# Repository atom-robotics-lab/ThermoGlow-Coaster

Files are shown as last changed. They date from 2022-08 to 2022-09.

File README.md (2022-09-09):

# Temperature Controlled LED Coaster



This project is an ESP12E based Temperature Controlled Smart Coaster. The project uses the following:
 * ESP12E Module
 * 12 x WS2812B SMD LEDs
 * MLX90614 Temperature Sensor I2C Module
 * Power Bank Charge-Boost Module for charging & boosting 3.7V of Li-Ion cell to 5V.
 * PCB Design was made using KICAD.

 This Project was made in Partnership with [hnhcart.com](https://www.hnhcart.com/) as sponsers and mentors.

 # Schematic
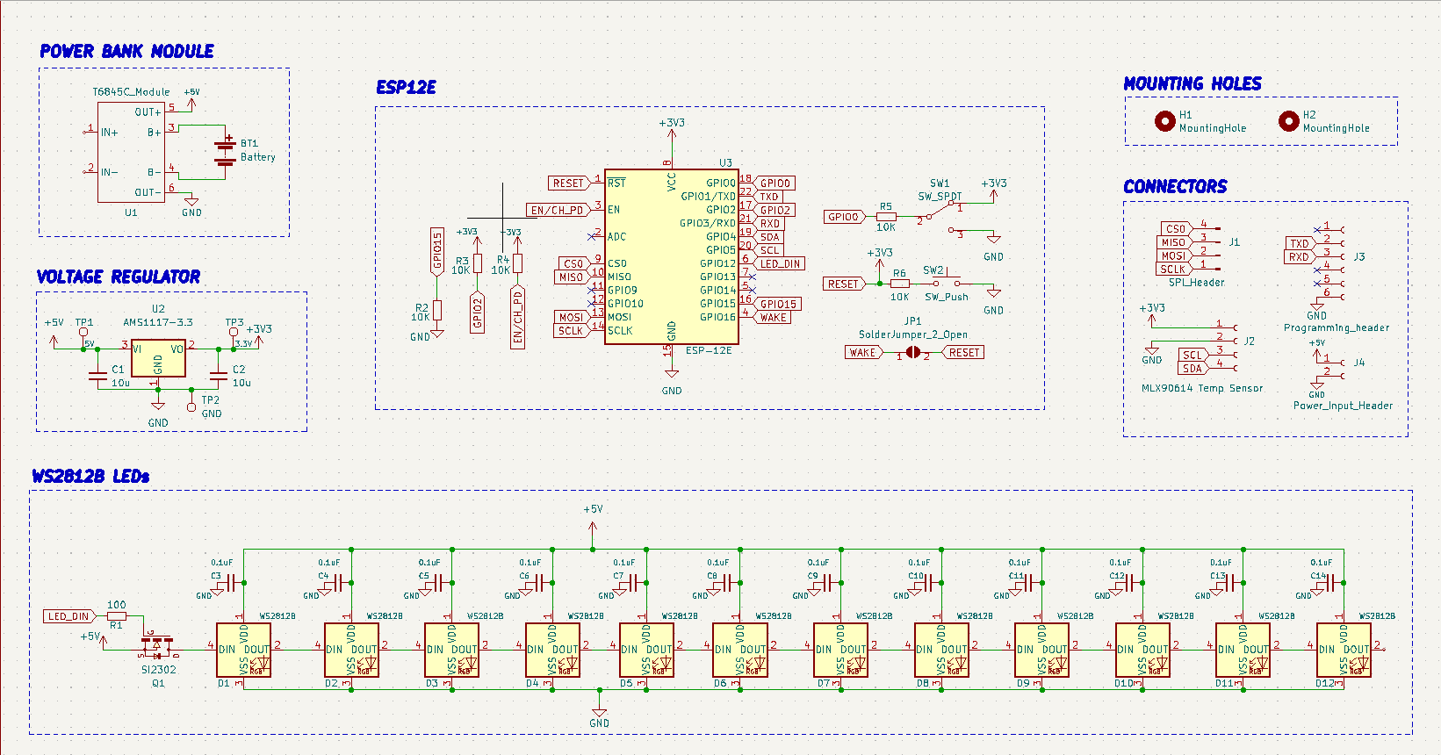
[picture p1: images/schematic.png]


# PCB Design
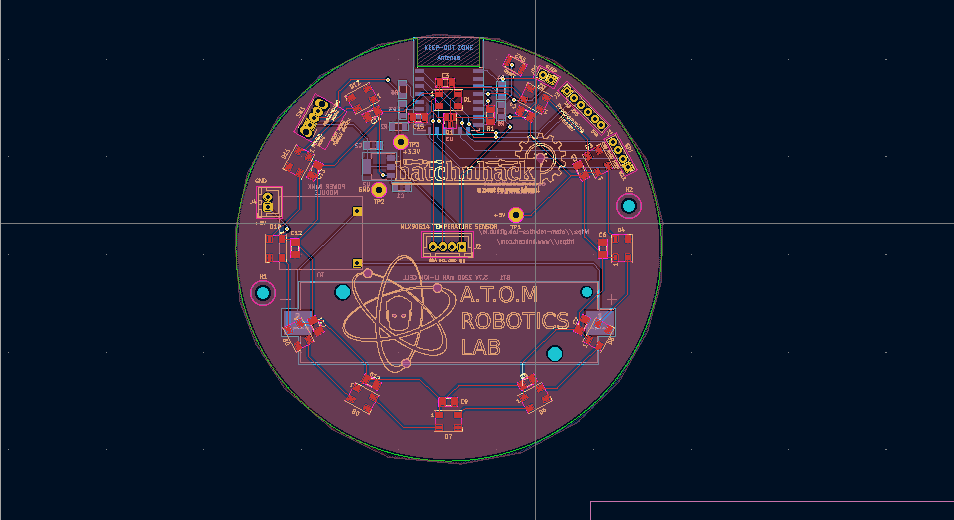
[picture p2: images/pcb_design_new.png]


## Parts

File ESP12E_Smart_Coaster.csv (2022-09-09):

Source: | /home/singh/projects/ESP12E_Smart_Coaster/ESP12E_Smart_Coaster.kicad_sch
Date: | Fri 09 Sep 2022 07:27:45 PM IST
Tool: | Eeschema 6.0.7-f9a2dced07~116~ubuntu20.04.1
Generator: | /usr/share/kicad/plugins/bom_csv_grouped_by_value_with_fp.py
Component Count: | 50
Ref | Qnty | Value | Cmp name | Footprint | Description | Vendor
BT1, | 1 | Battery | Battery | Battery:BatteryHolder_Keystone_1042_1x18650 | Multiple-cell battery
C1, C2, | 2 | 10u | C_Small | Capacitor_SMD:C_1206_3216Metric_Pad1.33x1.80mm_HandSolder | Unpolarized capacitor, small symbol
C3, C4, C5, C6, C7, C8, C9, C10, C11, C12, C13, C14, | 12 | 0.1uF | C_Small | Capacitor_SMD:C_1206_3216Metric_Pad1.33x1.80mm_HandSolder | Unpolarized capacitor, small symbol
C15, | 1 | 100uF | C_Small | Capacitor_SMD:C_1206_3216Metric_Pad1.33x1.80mm_HandSolder | Unpolarized capacitor, small symbol
D1, D2, D3, D4, D5, D6, D7, D8, D9, D10, D11, D12, | 12 | WS2812B | WS2812B | LED_SMD:LED_WS2812B_PLCC4_5.0x5.0mm_P3.2mm | RGB LED with integrated controller
H1, H2, | 2 | MountingHole | MountingHole | MountingHole:MountingHole_3.2mm_M3 | Mounting Hole without connection
J1, | 1 | SPI_Header | Conn_01x04_Male | Connector_PinHeader_2.54mm:PinHeader_1x04_P2.54mm_Vertical | Generic connector, single row, 01x04, script generated (kicad-library-utils/schlib/autogen/connector/)
J2, | 1 | MLX90614 Temp Sensor | Conn_01x04_Female | Connector_JST:JST_XH_B4B-XH-A_1x04_P2.50mm_Vertical | Generic connector, single row, 01x04, script generated (kicad-library-utils/schlib/autogen/connector/)
J3, | 1 | Programming_header | Conn_01x06_Female | Connector_PinSocket_2.54mm:PinSocket_1x06_P2.54mm_Vertical | Generic connector, single row, 01x06, script generated (kicad-library-utils/schlib/autogen/connector/)
J4, | 1 | Power_Input_Header | Conn_01x02_Female | Connector_JST:JST_XH_B2B-XH-A_1x02_P2.50mm_Vertical | Generic connector, single row, 01x02, script generated (kicad-library-utils/schlib/autogen/connector/)
JP1, | 1 | SolderJumper_2_Open | SolderJumper_2_Open | Connector_PinHeader_2.54mm:PinHeader_1x02_P2.54mm_Vertical | Solder Jumper, 2-pole, open
Q1, | 1 | SI2302 | SI2302 | Package_TO_SOT_SMD:SOT-23
R1, | 1 | 100 | R_Small | Resistor_SMD:R_1206_3216Metric_Pad1.30x1.75mm_HandSolder | Resistor, small symbol
R2, R3, R4, R5, R6, | 5 | 10K | R_Small | Resistor_SMD:R_1206_3216Metric_Pad1.30x1.75mm_HandSolder | Resistor, small symbol
SW1, | 1 | SW_SPDT | SW_SPDT | Button_Switch_THT:SW_CuK_OS102011MA1QN1_SPDT_Angled | Switch, single pole double throw
SW2, | 1 | SW_Push | SW_Push | Button_Switch_SMD:SW_Push_SPST_NO_Alps_SKRK | Push button switch, generic, two pins
TP1, | 1 | 5V | TestPoint | TestPoint:TestPoint_Loop_D2.54mm_Drill1.5mm_Beaded | test point
TP2, | 1 | GND | TestPoint | TestPoint:TestPoint_Loop_D2.54mm_Drill1.5mm_Beaded | test point
TP3, | 1 | 3.3V | TestPoint | TestPoint:TestPoint_Loop_D2.54mm_Drill1.5mm_Beaded | test point
U1, | 1 | T6845C_Module | T6845C_Module | Power_Bank_Module:T6845C_Module
U2, | 1 | AMS1117-3.3 | AMS1117-3.3 | Package_TO_SOT_SMD:SOT-223-3_TabPin2 | 1A Low Dropout regulator, positive, 3.3V fixed output, SOT-223
U3, | 1 | ESP-12E | ESP-12E | RF_Module:ESP-12E | 802.11 b/g/n Wi-Fi Module

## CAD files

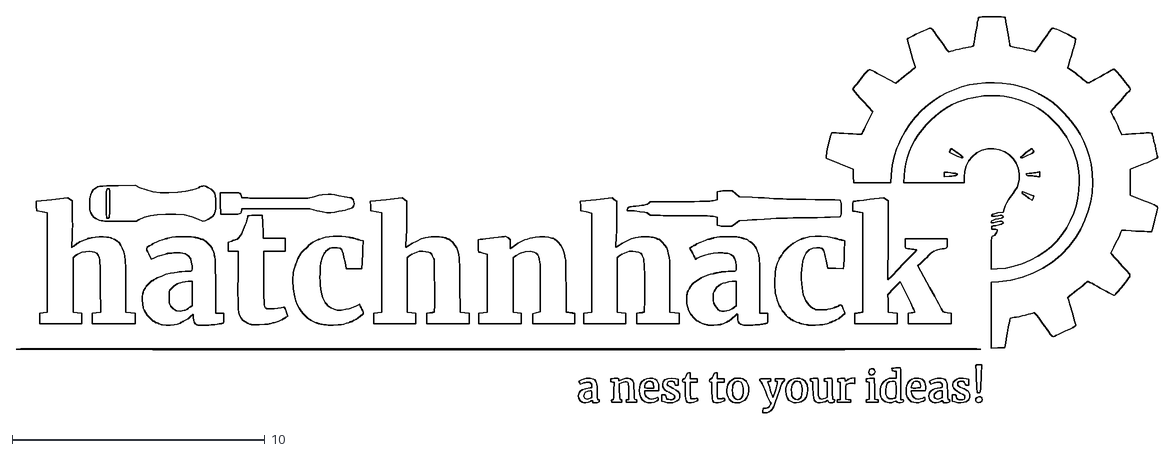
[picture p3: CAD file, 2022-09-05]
images/hatchnhack_logo2_1.5inch.dxf
45.2 x 15.7

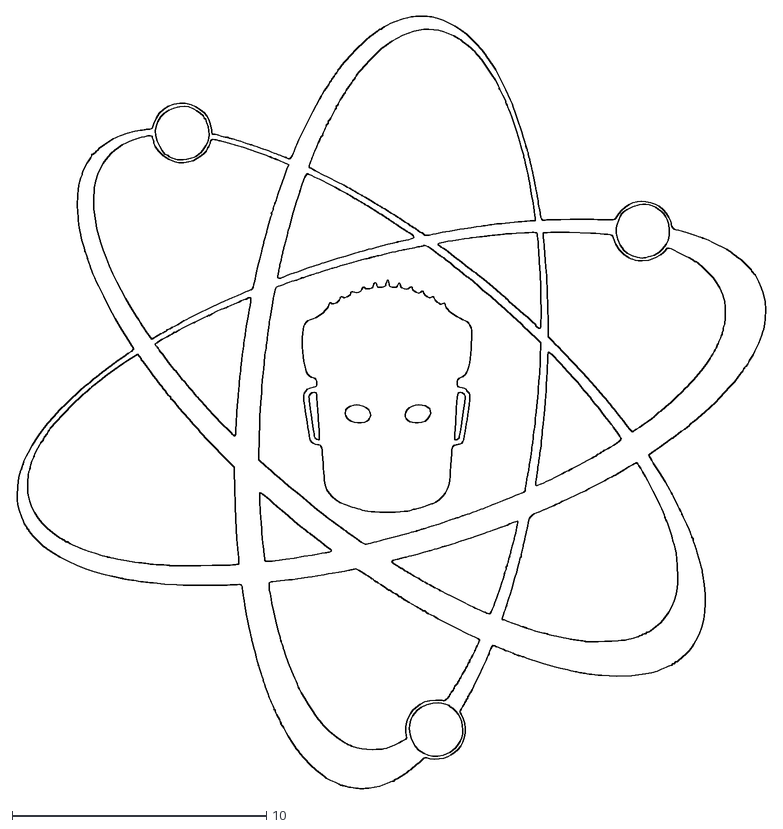
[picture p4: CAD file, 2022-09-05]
images/atom_logo.dxf
29.5 x 30.4

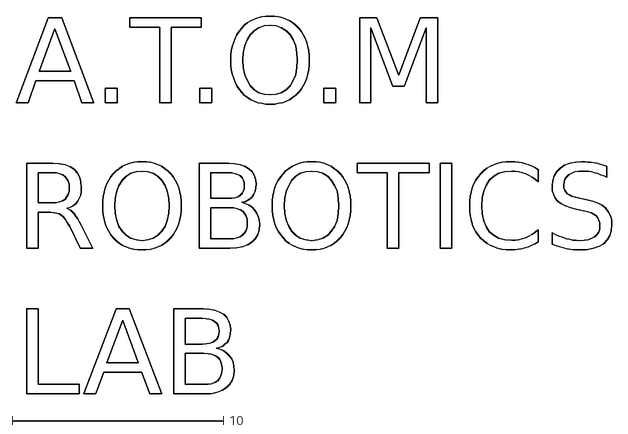
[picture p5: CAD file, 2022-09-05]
images/atom_name.dxf
28.2 x 17.9

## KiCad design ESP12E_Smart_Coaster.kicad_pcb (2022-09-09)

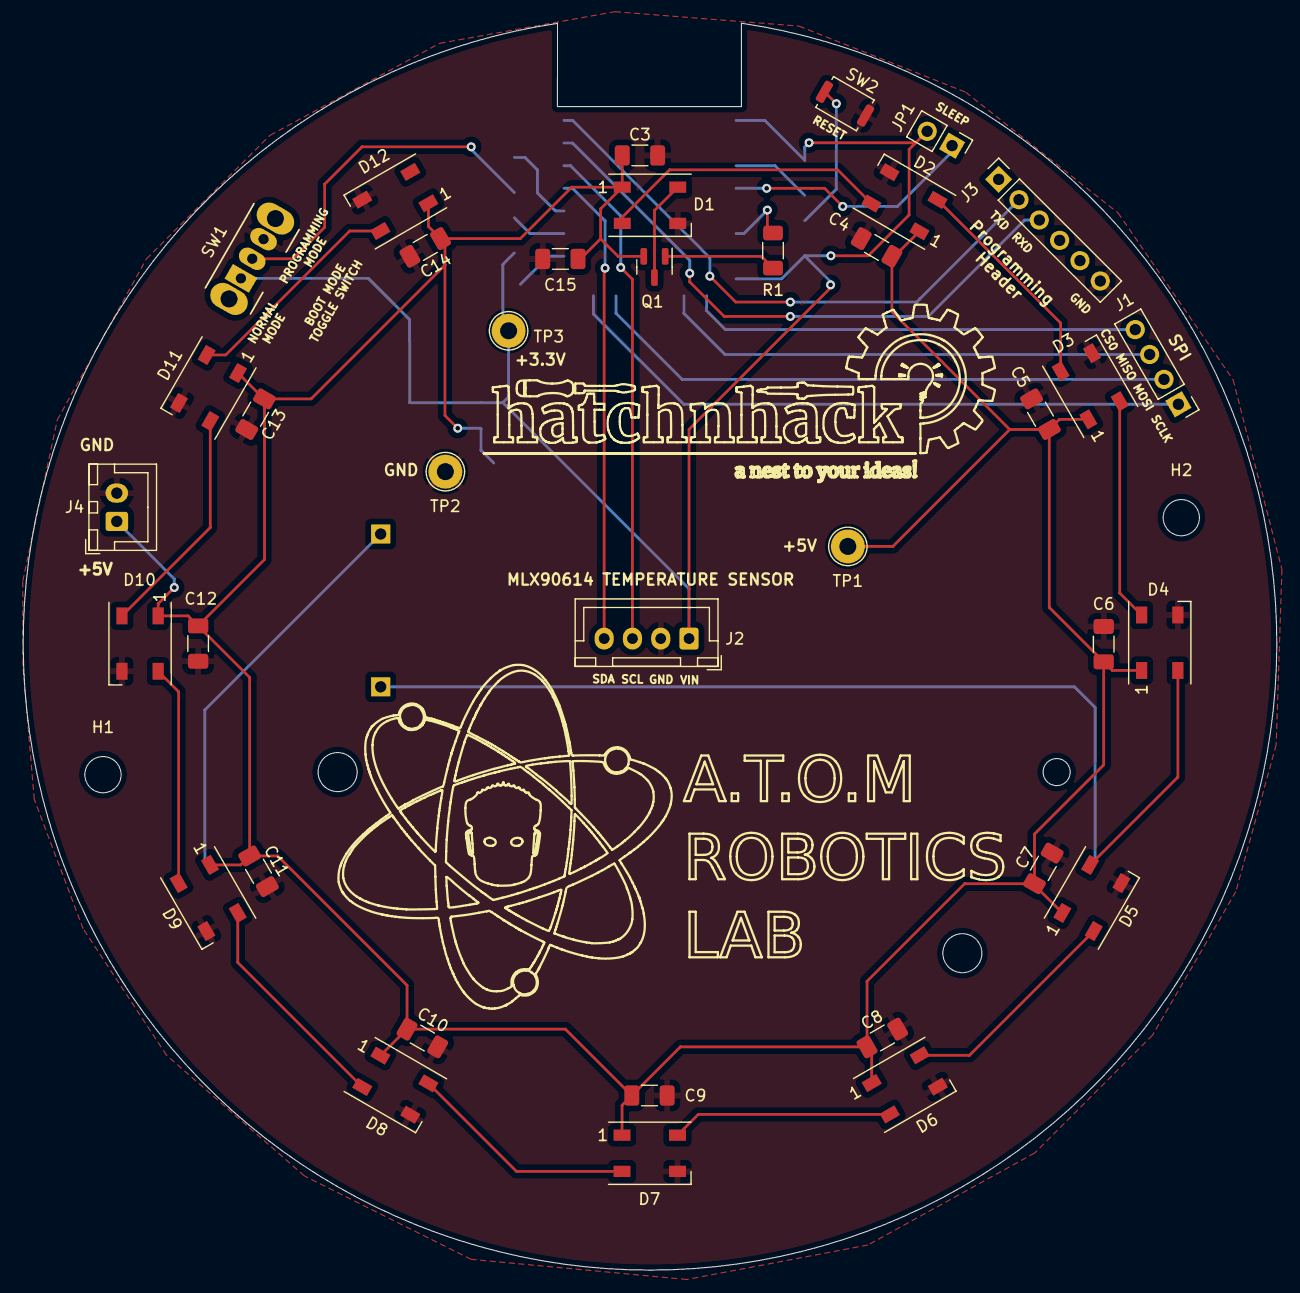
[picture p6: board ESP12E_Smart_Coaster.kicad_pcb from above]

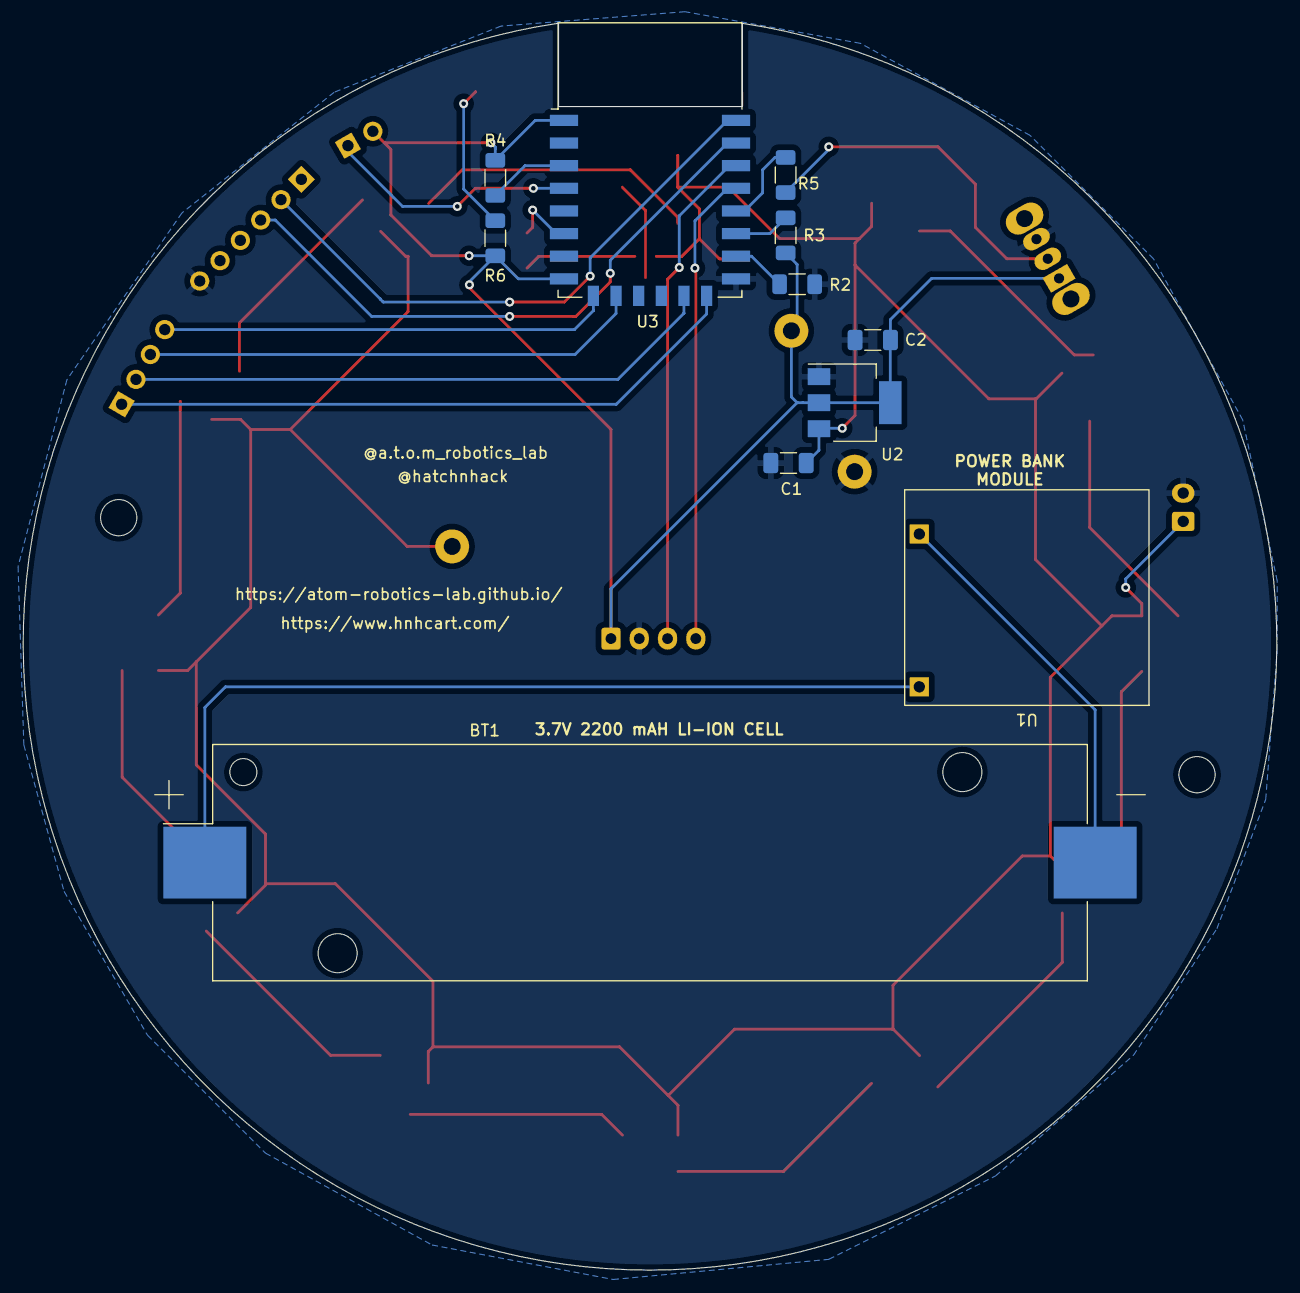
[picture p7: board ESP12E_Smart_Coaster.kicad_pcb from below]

Board: 2 copper layers, 110.8 x 110.2 mm, 50 parts (11 on the bottom side), 34 nets.

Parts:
BT1: Battery; BatteryHolder_Keystone_1042_1x18650
C1, C2: 10u; C_1206_3216Metric_Pad1.33x1.80mm_HandSolder
C3, C4, C5, C6, C7, C8, C9, C10, C11, C12, C13, C14: 0.1uF; C_1206_3216Metric_Pad1.33x1.80mm_HandSolder
C15: 100uF; C_1206_3216Metric_Pad1.33x1.80mm_HandSolder
D1, D2, D3, D4, D5, D6, D7, D8, D9, D10, D11, D12: WS2812B; LED_WS2812B_PLCC4_5.0x5.0mm_P3.2mm
H1, H2: MountingHole; MountingHole_3.2mm_M3
J1: SPI_Header; PinHeader_1x04_P2.54mm_Vertical
J2: MLX90614 Temp Sensor; JST_XH_B4B-XH-A_1x04_P2.50mm_Vertical
J3: Programming_header; PinSocket_1x06_P2.54mm_Vertical
J4: Power_Input_Header; JST_XH_B2B-XH-A_1x02_P2.50mm_Vertical
JP1: SolderJumper_2_Open; PinHeader_1x02_P2.54mm_Vertical
Q1: SI2302; SOT-23
R1: 100; R_1206_3216Metric_Pad1.30x1.75mm_HandSolder
R2, R3, R4, R5, R6: 10K; R_1206_3216Metric_Pad1.30x1.75mm_HandSolder
SW1: SW_SPDT; SW_CuK_OS102011MA1QN1_SPDT_Angled
SW2: SW_Push; SW_Push_SPST_NO_Alps_SKRK
TP1: 5V; TestPoint_Loop_D2.54mm_Drill1.5mm_Beaded
TP2: GND; TestPoint_Loop_D2.54mm_Drill1.5mm_Beaded
TP3: 3.3V; TestPoint_Loop_D2.54mm_Drill1.5mm_Beaded
U1: T6845C_Module
U2: AMS1117-3.3; SOT-223-3_TabPin2
U3: ESP-12E

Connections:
+5V: C1.1, C3.1, C4.1, C5.1, C6.1, C7.1, C8.1, C9.1, C10.1, C11.1, C12.1, C13.1, C14.1, C15.1, D1.1 (VDD), D2.1 (VDD), D3.1 (VDD), D4.1 (VDD), D5.1 (VDD), D6.1 (VDD), D7.1 (VDD), D8.1 (VDD), D9.1 (VDD), D10.1 (VDD), D11.1 (VDD), D12.1 (VDD), J4.1, Q1.2, TP1.1, U2.3 (VI)
CS0: J1.4, U3.9 (CS0)
EN/CH_PD: R4.2, U3.3 (EN)
GND: C1.2, C2.2, C3.2, C4.2, C5.2, C6.2, C7.2, C8.2, C9.2, C10.2, C11.2, C12.2, C13.2, C14.2, C15.2, D1.3 (VSS), D2.3 (VSS), D3.3 (VSS), D4.3 (VSS), D5.3 (VSS), D6.3 (VSS), D7.3 (VSS), D8.3 (VSS), D9.3 (VSS), D10.3 (VSS), D11.3 (VSS), D12.3 (VSS), J2.2, J3.6, J4.2, R2.2, SW1.3 (C), SW2.2, TP2.1, U2.1 (GND), U3.15 (GND)
GPIO0: R5.2, U3.18 (GPIO0)
GPIO2: R3.2, U3.17 (GPIO2)
GPIO15: R2.1, U3.16 (GPIO15)
LED_DIN: R1.1, U3.6 (GPIO12)
MISO: J1.3, U3.10 (MISO)
MOSI: J1.2, U3.13 (MOSI)
unnamed: BT1.1 (+), U1.3 (B+)
unnamed: BT1.2 (-), U1.4 (B-)
unnamed: D1.2 (DOUT), D2.4 (DIN)
unnamed: D1.4 (DIN), Q1.3
unnamed: D2.2 (DOUT), D3.4 (DIN)
unnamed: D3.2 (DOUT), D4.4 (DIN)
unnamed: D4.2 (DOUT), D5.4 (DIN)
unnamed: D5.2 (DOUT), D6.4 (DIN)
unnamed: D6.2 (DOUT), D7.4 (DIN)
unnamed: D7.2 (DOUT), D8.4 (DIN)
unnamed: D8.2 (DOUT), D9.4 (DIN)
unnamed: D10.2 (DOUT), D11.4 (DIN)
unnamed: D9.2 (DOUT), D10.4 (DIN)
unnamed: D11.2 (DOUT), D12.4 (DIN)
unnamed: Q1.1, R1.2
unnamed: R5.1, SW1.2 (B)
unnamed: R6.2, SW2.1
RESET: C2.1, J2.1, JP1.2 (B), R3.1, R4.1, R6.1, SW1.1 (A), TP3.1, U2.2 (VO), U3.1 (~RST), U3.8 (VCC)
RXD: J3.3, U3.21 (GPIO3/RXD)
SCL: J2.3, U3.20 (GPIO5)
SCLK: J1.1, U3.14 (SCLK)
SDA: J2.4, U3.19 (GPIO4)
TXD: J3.2, U3.22 (GPIO1/TXD)
WAKE: JP1.1 (A), U3.4 (GPIO16)

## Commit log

2022-05-15 Revert "add mc34063AP"
    This reverts commit ce2e4ae2c6462f3cc229f7f57adec7c62f3c656d.
    [esp_coaster.sch]
2022-05-20 Deleted eagle files
    [esp_coaster.sch]
2022-05-20 Adds KiCAD files
    [ESP12E_Smart_Coaster.kicad_pcb, ESP12E_Smart_Coaster.kicad_sch]
2022-05-25 Adds WS2812B Leds & Logic Level Shifter in schematic
    [ESP12E_Smart_Coaster.kicad_sch]
2022-05-27 Adds 0.1uF cap to WS2812B LEDs
    [ESP12E_Smart_Coaster.kicad_sch]
2022-05-27 Adds library for power bank module and symbol in schematic
    [ESP12E_Smart_Coaster.kicad_sch]
2022-08-16 Adds footprints for components
    [ESP12E_Smart_Coaster.kicad_sch]
2022-08-19 added footprint for spdt and push switches
    [ESP12E_Smart_Coaster.kicad_sch]
2022-08-22 Started component placement
    [ESP12E_Smart_Coaster.kicad_pcb, ESP12E_Smart_Coaster.kicad_sch]
2022-08-22 re-arrange components but not completely done
    [ESP12E_Smart_Coaster.kicad_pcb]
2022-08-22 Started PCB routing
    [ESP12E_Smart_Coaster.kicad_pcb, ESP12E_Smart_Coaster.kicad_sch]
2022-08-27 Added power connector and wake jumper
    [ESP12E_Smart_Coaster.kicad_pcb, ESP12E_Smart_Coaster.kicad_sch]
2022-08-27 routing changes
    [ESP12E_Smart_Coaster.kicad_pcb]
2022-08-28 Changed connector positions
    [ESP12E_Smart_Coaster.kicad_pcb]
2022-09-05 Added graphics
    [ESP12E_Smart_Coaster.kicad_pcb, ESP12E_Smart_Coaster.kicad_sch, atom_logo.dxf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]
2022-09-05 Deleted pcb ss
2022-09-09 Added gerber files
    [ESP12E_Smart_Coaster-B_Cu.gbl, ESP12E_Smart_Coaster-B_Mask.gbs, ESP12E_Smart_Coaster-B_Silkscreen.gbo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]
2022-09-09 Adds BOM
    [ESP12E_Smart_Coaster.csv]
2023-10-24 Added PCB step file
